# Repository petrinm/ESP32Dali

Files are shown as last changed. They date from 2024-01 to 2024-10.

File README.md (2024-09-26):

# ESP32Dali

ESP32Dali is project to interface with [DALI](https://en.wikipedia.org/wiki/Digital_Addressable_Lighting_Interface) compatible lighting devices using [ESPHome](https://esphome.io/) project. The board supports isolated communication to DALI bus as a master device and the board can also work as 18V DALI power supply from single 5V supply. ESP32Dali is a single 2-layer matchbox sized PCB to host ESP32-WROOM-32 and required interfacing components. The schematics and board files are in the `hw` folder ([KiCanvas](https://kicanvas.org/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), [pdf](https://github.com/petrinm/ESP32Dali/blob/main/hw/ESPDali.pdf)) 3D step files and printed enclosure are also available. The software is based on ESPHome project and its installation is documented in the software README.

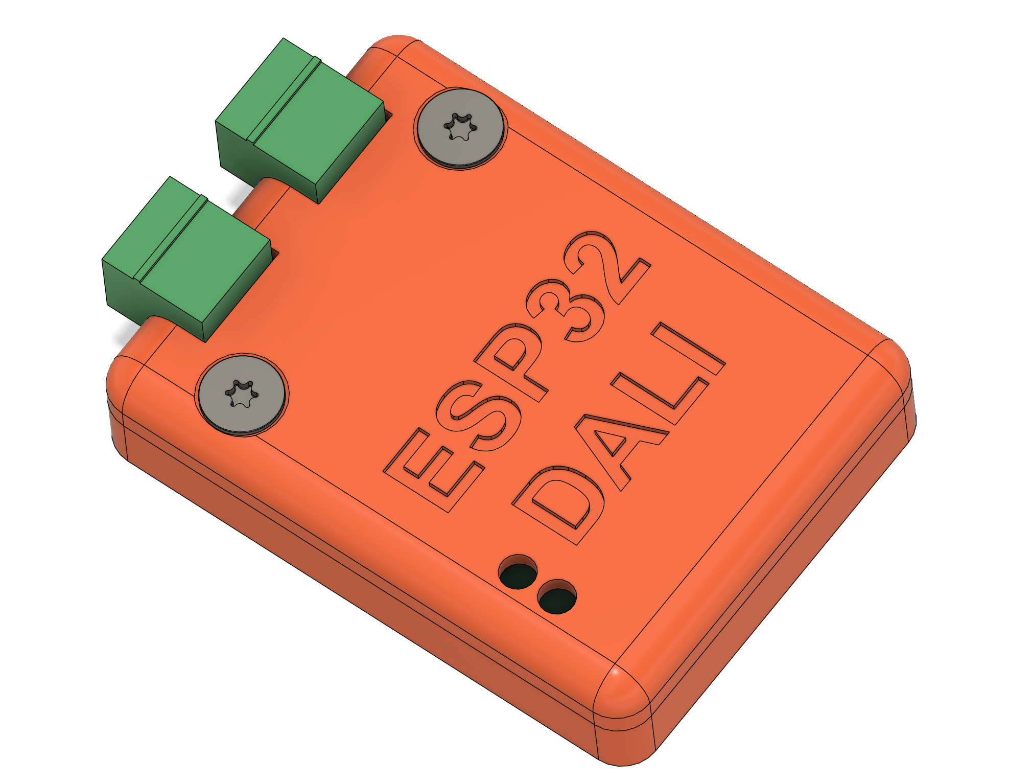
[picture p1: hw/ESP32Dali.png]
ESP32Dali

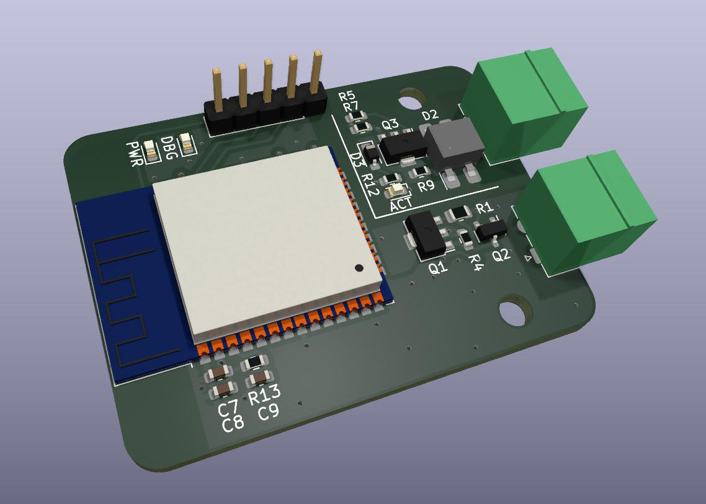
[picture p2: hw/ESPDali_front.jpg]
ESP32Dali front side

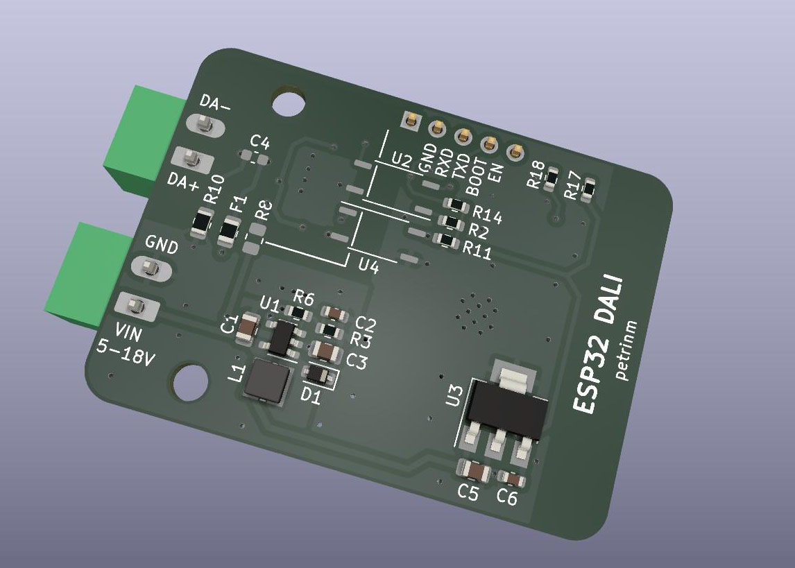
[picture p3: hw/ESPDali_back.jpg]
ESP32Dali back side


The project is licenced under MIT license.

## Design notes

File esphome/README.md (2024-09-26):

# Example configuration

```yaml
light:
  - platform: monochrome
    name: "LED strip"
    output: dali_output

dali:
  id: dali_if
  tx_pin:
    number: 17
    inverted: true
  rx_pin:
    number: 16
    inverted: true

output:
  - platform: dali
    id: dali_output
    interface: dali_if
    address: 5

```

Run
```bash
$ esphome run livingroom.yaml
```

## Installing ESP32Dali as external component

https://esphome.io/components/external_components

```yaml
external_components:
  - source:
      type: git
      url: https://github.com/petrinm/ESP32Dali.git
    components: [ dali ]
```

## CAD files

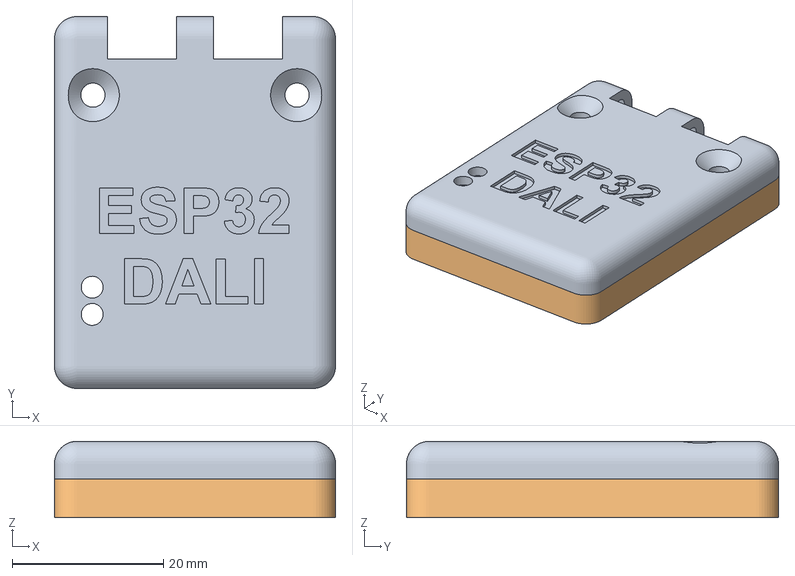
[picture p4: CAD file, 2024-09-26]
3d/Top.3mf
37.2 x 49.2 x 10.1 mm

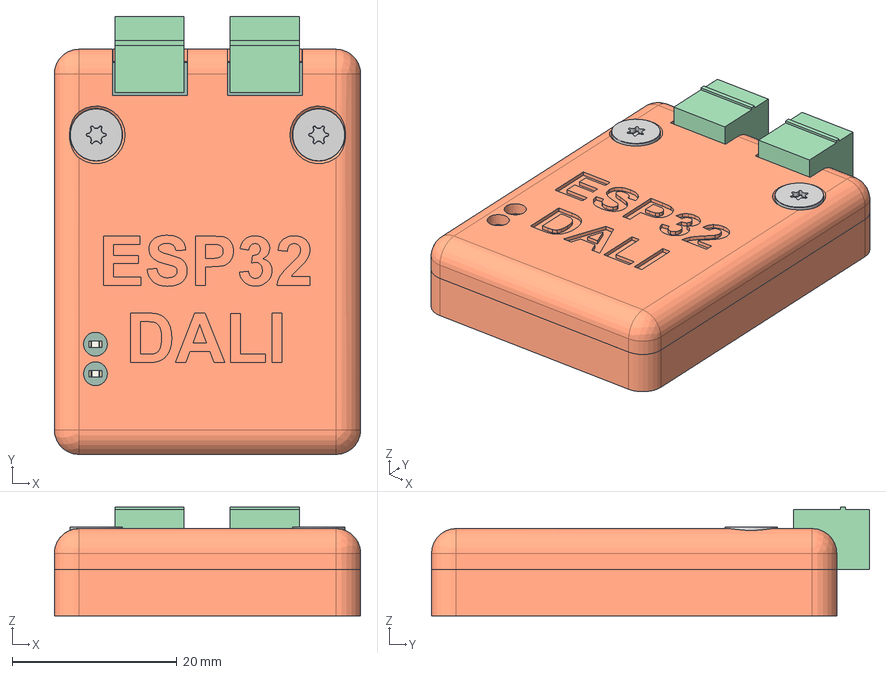
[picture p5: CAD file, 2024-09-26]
3d/ESP32Dali.step
37.2 x 53.2 x 13.2 mm
Top
ESPDali PCB
Bottom
94331A104_NO THREADS_High-Strength A286 Stainless Steel Torx Flat Hea d Screw x 2

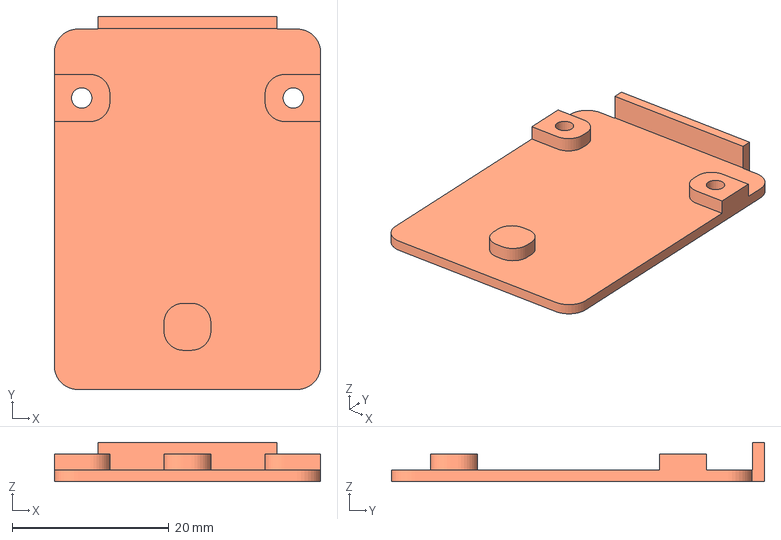
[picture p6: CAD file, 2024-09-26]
3d/Bottom.3mf
34.0 x 47.6 x 5.00 mm

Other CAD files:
3d/ESP32Dali.f3z

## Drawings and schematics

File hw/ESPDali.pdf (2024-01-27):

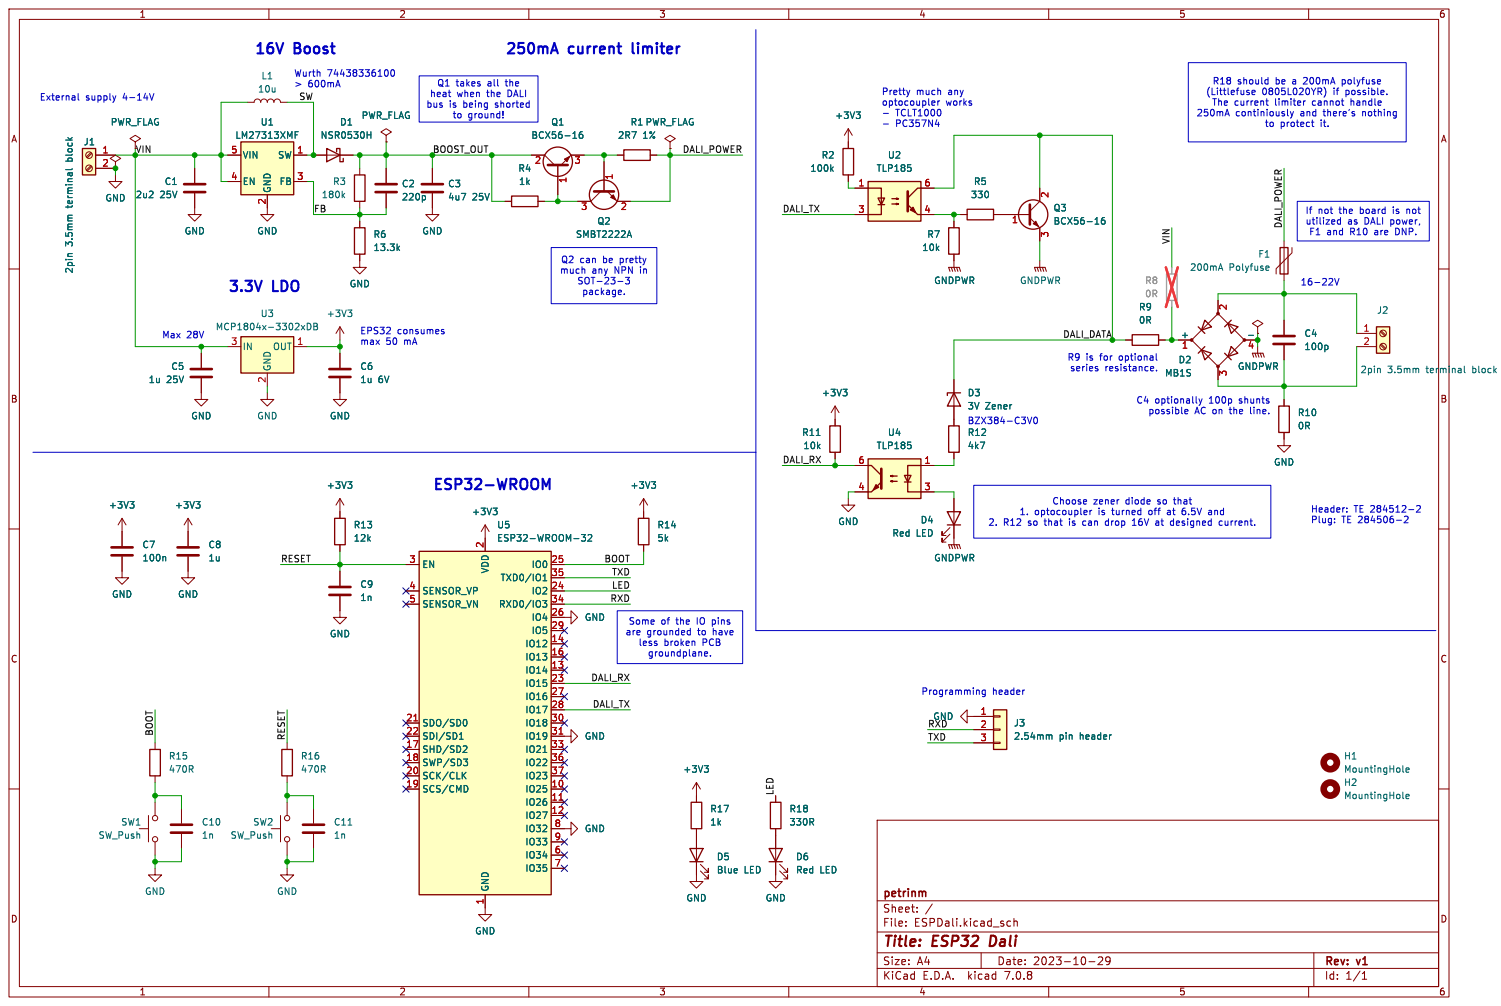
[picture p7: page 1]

2. R12 so that is can drop 16V at designed current. Q1 takes all the
heat when the DALI bus is being shorted

to protect it. Some of the IO pins are grounded to have

2 SCK/CLK 20 SDO/SD0 21 SDI/SD1 22

Id: 1/1 Title: ESP32 Dali File: ESPDali.kicad_sch Sheet: / petrinm

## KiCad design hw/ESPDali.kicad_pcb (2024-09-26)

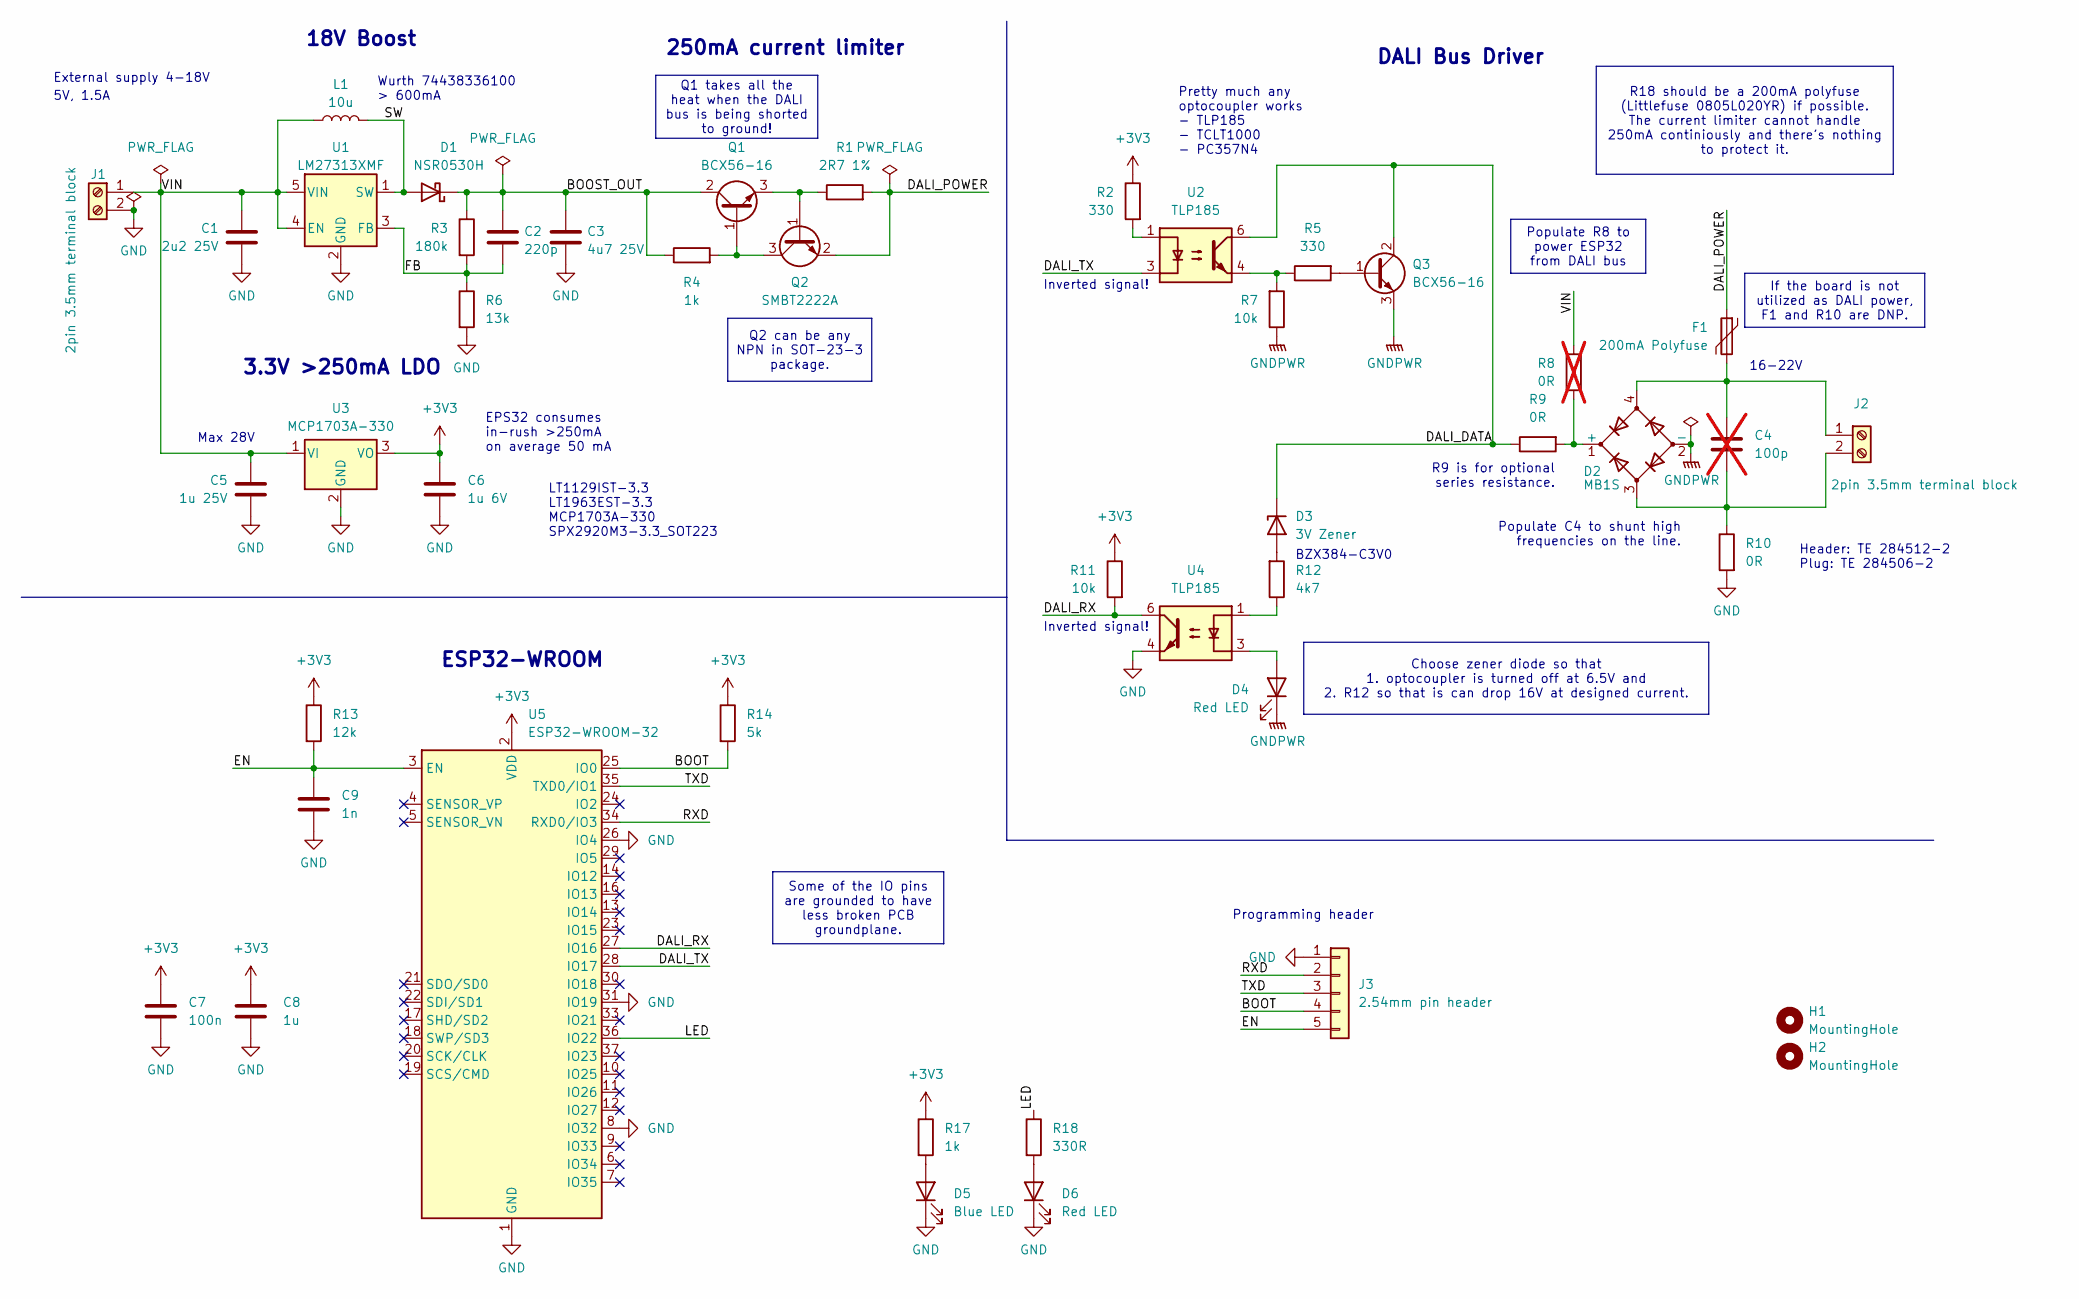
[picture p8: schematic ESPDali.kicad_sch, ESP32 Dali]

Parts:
C1: 2u2 25V; C_0805_2012Metric
C2: 220p; C_0603_1608Metric
C3: 4u7 25V; C_0805_2012Metric
C4: 100p; C_0603_1608Metric; not fitted
C5: 1u 25V; C_0805_2012Metric
C6: 1u 6V; C_0603_1608Metric
C7: 100n; C_0603_1608Metric
C8: 1u; C_0603_1608Metric
C9: 1n; C_0603_1608Metric
D1: NSR0530H; D_SOD-323
D2: MB1S
D3: 3V Zener; D_SOD-323
D4, D6: Red LED; LED_0603_1608Metric
D5: Blue LED; LED_0603_1608Metric
F1: 200mA Polyfuse; Fuse_0805_2012Metric
H1, H2: MountingHole; MountingHole_3.2mm_M3
J1, J2: 2pin 3.5mm terminal block; PhoenixContact_MC_1,5_2-G-3.5_1x02_P3.50mm_Horizontal
J3: 2.54mm pin header; PinHeader_1x05_P2.54mm_Vertical
L1: 10u; L_Wuerth_MAPI-3020
Q1, Q3: BCX56-16; SOT-89-3
Q2: SMBT2222A; SOT-23
R1: 2R7 1%; R_0805_2012Metric
R2, R5: 330; R_0603_1608Metric
R3: 180k; R_0603_1608Metric
R4, R17: 1k; R_0603_1608Metric
R6: 13k; R_0603_1608Metric
R7, R11: 10k; R_0603_1608Metric
R8: 0R; R_0805_2012Metric; not fitted
R9: 0R; R_0603_1608Metric
R10: 0R; R_0805_2012Metric
R12: 4k7; R_0603_1608Metric
R13: 12k; R_0603_1608Metric
R14: 5k; R_0603_1608Metric
R18: 330R; R_0603_1608Metric
U1: LM27313XMF; SOT-23-5
U2, U4: TLP185; SOIC-4_4.55x3.7mm_P2.54mm
U3: MCP1703A-330; SOT-223-3_TabPin2
U5: ESP32-WROOM-32

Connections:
+3V3: C6.1, C7.1, C8.1, R2.1, R11.1, R13.1, R14.1, R17.1, U3.3 (VO), U5.2 (VDD)
/BOOST_OUT: C2.1, C3.1, D1.1 (K), Q1.2 (C), R3.1, R4.1
/BOOT: J3.4, R14.2, U5.25 (IO0)
/DALI_DATA: D3.1 (K), Q3.2 (C), R9.1, U2.6
/DALI_POWER: F1.1, Q2.2 (E), R1.2
/DALI_RX: R11.2, U4.6, U5.27 (IO16)
/DALI_TX: U2.3, U5.28 (IO17)
/EN: C9.1, J3.5, R13.2, U5.3 (EN)
/FB: C2.2, R3.2, R6.1, U1.3 (FB)
/LED: R18.1, U5.36 (IO22)
/RXD: J3.2, U5.34 (RXD0/IO3)
/SW: D1.2 (A), L1.2, U1.1 (SW)
/TXD: J3.3, U5.35 (TXD0/IO1)
/VIN: C1.1, C5.1, J1.1, L1.1, R8.1, U1.4 (EN), U1.5 (VIN), U3.1 (VI)
GND: C1.2, C3.2, C5.2, C6.2, C7.2, C8.2, C9.2, D5.1 (K), D6.1 (K), J1.2, J3.1, R6.2, R10.2, U1.2 (GND), U3.2 (GND), U4.4, U5.1 (GND), U5.8 (IO32), U5.15 (GND), U5.26 (IO4), U5.31 (IO19), U5.38 (GND), U5.39 (GND)
GNDPWR: D2.2 (-), D4.1 (K), Q3.3 (E), R7.1
unnamed: D2.1 (+), R8.2, R9.2
unnamed: D3.2 (A), R12.2
unnamed: D4.2 (A), U4.3
unnamed: D5.2 (A), R17.2
unnamed: D6.2 (A), R18.2
unnamed: C4.1, D2.4, F1.2, J2.1
unnamed: C4.2, D2.3, J2.2, R10.1
unnamed: Q1.1 (B), Q2.3 (C), R4.2
unnamed: Q1.3 (E), Q2.1 (B), R1.1
unnamed: Q3.1 (B), R5.2
unnamed: R2.2, U2.1
unnamed: R5.1, R7.2, U2.4
unnamed: R12.1, U4.1

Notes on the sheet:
Q1 takes all the heat when the DALI bus is being shorted to ground!
Choose zener diode so that 1. optocoupler is turned off at 6.5V and 2. R12 so that is can drop 16V at designed current.
Q2 can be any NPN in SOT-23-3 package.
If the board is not utilized as DALI power, F1 and R10 are DNP.
Populate R8 to power ESP32 from DALI bus
R18 should be a 200mA polyfuse (Littlefuse 0805L020YR) if possible. The current limiter cannot handle 250mA continiously and there's nothing to protect it.
Some of the IO pins are grounded to have less broken PCB groundplane.
Pretty much any optocoupler works - TLP185 - TCLT1000 - PC357N4
ESP32-WROOM
16-22V
EPS32 consumes in-rush >250mA on average 50 mA
DALI Bus Driver
Populate C4 to shunt high frequencies on the line.
BZX384-C3V0
Wurth 74438336100 > 600mA
Inverted signal!
250mA current limiter
5V, 1.5A
Programming header
Max 28V
R9 is for optional series resistance.
3.3V >250mA LDO
External supply 4-18V
Header: TE 284512-2 Plug: TE 284506-2
18V Boost
LT1129IST-3.3 LT1963EST-3.3 MCP1703A-330 SPX2920M3-3.3_SOT223

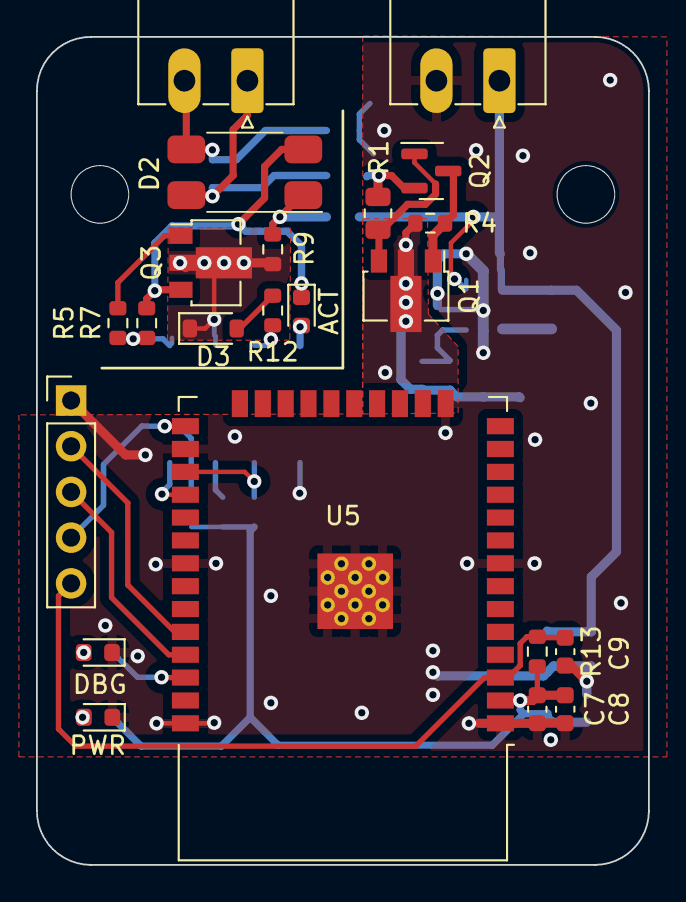
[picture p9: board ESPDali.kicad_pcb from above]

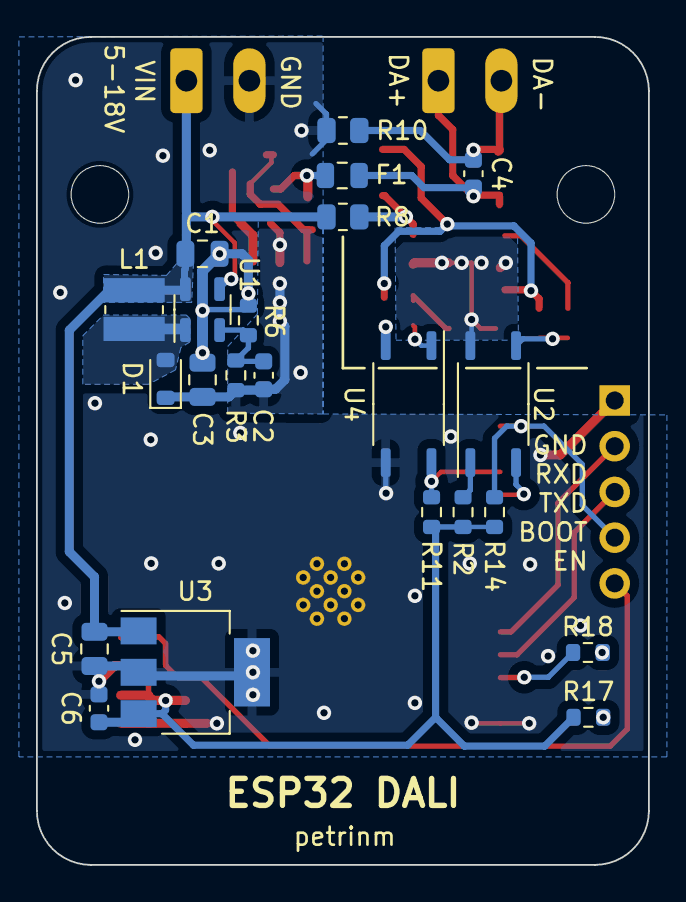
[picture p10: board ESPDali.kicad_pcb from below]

Board: 2 copper layers, 34.0 x 46.0 mm, 46 parts (22 on the bottom side), 29 nets.

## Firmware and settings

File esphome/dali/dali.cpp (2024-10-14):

#if defined(USE_ARDUINO) && defined(USE_ESP32)

#include "dali.h"
#include "dali_cmds.h"
#include "esphome/core/helpers.h"
#include "esphome/core/log.h"
#include "driver/timer.h"



namespace esphome {
namespace DALI {

static const char *TAG = "dali_interface";


/*******************************************************************************
 * Typedefs and defines
 ******************************************************************************/

#define BI_PHASE_HIGH           0b01
#define BI_PHASE_LOW            0b10
#define BI_PHASE_MASK           0b11


/*******************************************************************************
 * Define DALI timing values. One Bit on a DALI bus is
 * 833.33µs (1200 bauds) which corresponds to 2TE.
 ******************************************************************************/

#define TE            (417)                     // half bit time = 417 usec

/* Transmission timing, option to compensate for unequal physical layer delay in rising or falling edge*/
#define TE_HIGH       (TE + 0)
#define TE_LOW        (TE - 0)

#define DALI_STOP_BIT_TIME          (4*TE)
#define MIN_FORWARD_FRAME_DELAY     (22*TE)     // minimum time between two forward frames - 9.17ms ==> 22 x TE time
#define BACKWARD_FRAME_DELAY        (12*TE)     // time between forward frame and backward frame >= 7TE

#if 0 /* strict receive timing according to specification  */
  #define MIN_TE      (TE - 42)                 // minimum half bit time
  #define MAX_TE      (TE + 42)                 // maximum half bit time
  #define MIN_2TE     (2*TE - 83)               // minimum full bit time
  #define MAX_2TE     (2*TE + 83)               // maximum full bit time
#else /* More relaxed receive timing */
  #define MIN_TE      (300)                     // minimum half bit time
  #define MAX_TE      (550)                     // maximum half bit time
  #define MIN_2TE     (2*TE - (2*(TE/5)))       // minimum full bit time
  #define MAX_2TE     (2*TE + (2*(TE/5)))       // maximum full bit time
#endif

#define BACKWARD_FRAME_BIT_LENGTH     18 // two byte commands have 34 bit in total (including start bit)



/* State machine states: */
typedef enum stateTag
{
  MS_IDLE = 0,                        // bus idle
  MS_TX_SECOND_HALF_START_BIT,        //
  MS_TX_DALI_FORWARD_FRAME,           // sending the dali forward frame
  MS_TX_STOP_BITS,                    //
  MS_SETTLING_BEFORE_BACKWARD,        // settling between forward and backward - stop bits
  MS_SETTLING_BEFORE_IDLE,            // settling before going to idle, after forward frame
  MS_WAITING_FOR_SLAVE_START_WINDOW,  // waiting for 7Te, start of slave Tx window
  MS_WAITING_FOR_SLAVE_START,         // start of slave Tx window
  MS_RECEIVING_ANSWER                 // receiving slave message
} MASTER_STATE;


void inline DALI_SetOutputHigh(DALIState* driver) {
  driver->tx_pin->digital_write(false); // INVERTED!!!
}

void inline DALI_SetOutputLow(DALIState *driver) {
  driver->tx_pin->digital_write(true); // INVERTED!!!
}

bool inline DALI_GetInput(DALIState *driver) {
  return driver->rx_pin->digital_read();
}


/// Run timer interrupt code and return in how many µs the next event is expected
/* the handling of the protocol is done in the IRQ */

DALIState *gbl_driver;

static void IRAM_ATTR HOT gpio_interrupt(DALIState *driver);

static void IRAM_ATTR HOT timer_interrupt() // DALIState *driver);
{
  DALIState *driver = gbl_driver;

  switch(driver->state)
  {
    case MS_TX_SECOND_HALF_START_BIT:
      /*
       * Sending start bit
       */
      DALI_SetOutputHigh(driver);
      driver->bitcount = 0;

      // Timer auto reloads and next waits TE
      driver->state = MS_TX_DALI_FORWARD_FRAME;

      break;

    case MS_TX_DALI_FORWARD_FRAME:
      /*
       * Sending coded data bits
       */
      if (driver->forward_frame & 0x80000000)
        DALI_SetOutputHigh(driver);
      else
        DALI_SetOutputLow(driver);

      driver->forward_frame <<= 1;
      driver->bitcount++;

      // End of data bits?
      if (driver->bitcount == 32)
        driver->state = MS_TX_STOP_BITS;

      // Timer auto reloads and next waits TE
      break;

    case MS_TX_STOP_BITS:
      /*
       * Sending stop bits
       */

      // High state to free the bus
      DALI_SetOutputHigh(driver);

      // The first half of the first stop bit has just been output.
      // Do we have to wait for an answer?
      if (driver->waitForAnswer)
      {
        // Elapse until the end of the last half of the second stop bit
        timerAlarmWrite(driver->timer, 4 * TE, false);

        driver->backward_frame = 0;
        driver->state = MS_SETTLING_BEFORE_BACKWARD;
      }
      else
      {
        // No answer from slave expected, need to wait for the remaining
        // bus idle time before next forward frame.
        // Add additional 3 TE to minimum specification to be not at the edge of the timing specification
        timerAlarmWrite(driver->timer, (4 + 22 + 3) * TE, false);
        driver->state = MS_SETTLING_BEFORE_IDLE;
      }
      break;

    case MS_SETTLING_BEFORE_BACKWARD:
      /*
       * Wait for
       */

      DALI_SetOutputHigh(driver);

      // Setup the first window limit for the slave answer.
      // The slave should not respond before 7TE.
      timerAlarmWrite(driver->timer, 7 * MIN_TE, false);

      // Enable capture on both edges.
      driver->rx_pin->attach_interrupt(&gpio_interrupt, driver, gpio::INTERRUPT_ANY_EDGE);

      driver->state = MS_WAITING_FOR_SLAVE_START_WINDOW;
      break;

    case MS_WAITING_FOR_SLAVE_START_WINDOW:
      /*
       *
       */

      // Setup the second window limit for the slave answer,
      // slave must start transmit within the next 23TE window.
      timerAlarmWrite(driver->timer, 23 * MAX_TE, false);
      driver->state = MS_WAITING_FOR_SLAVE_START;

      // Next we should receive GPIO interrupts
      break;

    case MS_WAITING_FOR_SLAVE_START:
      /*
       * Receive timeout. Nothing was received
       */

      // If we still get here, got 'no' or too early answer from slave
      // idle time of 23TE was already elapsed while waiting, so
      // immediately release the bus.

      // Reset and stop the timer
      timerStop(driver->timer);

      // Disable capture
      driver->rx_pin->detach_interrupt();

      // Execution returns to Do_transfer function
      driver->state = MS_IDLE;
      break;

    case MS_RECEIVING_ANSWER:
      /*
       * Receive timeout in middle of frame
       */

      // Stop receiving
      // Now idle the bus between backward and next forward frame
      // since we don't track the last edge of received frame,
      // conservatively we wait for 23 TE (>= 22 TE as for specification).
      // Receive interval considered anyway the max tolerance for
      // backward frame duration so >22TE should already be asserted.
      timerAlarmWrite(driver->timer, 23 * TE, false);
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

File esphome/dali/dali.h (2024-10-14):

#pragma once

#if defined(USE_ARDUINO) && defined(USE_ESP32)

#include "esphome/core/component.h"
#include "esphome/core/gpio.h"
#include "esphome/core/hal.h"

#include "esphome/components/esp32/gpio.h"

#include <esp32-hal-timer.h>


namespace esphome {
namespace DALI {


struct DALIState {

  // Current state
  unsigned int state;

  // Manchester coded forward frame
  uint32_t forward_frame;

  // Bit counter
  uint32_t bitcount;

  // Flag to indicate wether a backward frame is expected
  bool waitForAnswer;

  // Received backwarf frame
  uint32_t backward_frame;

  // Transmitter pin
  InternalGPIOPin *tx_pin;

  // Receiver pin
  InternalGPIOPin *rx_pin;

  // Timer
  hw_timer_t *timer;

};

/* DT8 Colour value defines (Part 209 Table 11) */
enum QueryColourValue
{
  XCoordinate = 0,
  YCoordinate = 1,
  ColourTemperatureTC = 2,
  PrimaryNDimLevel0 = 3,
  PrimaryNDimLevel1 = 4,
  PrimaryNDimLevel2 = 5,
  PrimaryNDimLevel3 = 6,
  PrimaryNDimLevel4 = 7,
  PrimaryNDimLevel5 = 8,
  RedDimLevel = 9,
  GreenDimLevel = 10,
  BlueDimLevel = 11,
  WhiteDimLevel = 12,
  AmberDimLevel = 13,
  FreecolourDimLevel = 14,
  RGBWAFControl = 15,
  XCoordinatePrimaryN0 = 64,
  YCoordinatePrimaryN0 = 65,
  TYPrimaryN0 = 66,
  XCoordinatePrimaryN1 = 67,
  YCoordinatePrimaryN1 = 68,
  TYPrimaryN1 = 69,
  XCoordinatePrimaryN2 = 70,
  YCoordinatePrimaryN2 = 71,
  TYPrimaryN2 = 72,
  XCoordinatePrimaryN3 = 73,
  YCoordinatePrimaryN3 = 74,
  TYPrimaryN3 = 75,
  XCoordinatePrimaryN4 = 76,
  YCoordinatePrimaryN4 = 77,
  TYPrimaryN4 = 78,
  XCoordinatePrimaryN5 = 79,
  YCoordinatePrimaryN5 = 80,
  TYPrimaryN5 = 81,
  NumberOfPrimaries = 82,
  ColourTemperatureTcCoolest = 128,
  ColourTemperatureTcPhysicalCoolest = 129,
  ColourTemperatureTcWarmest = 130,
  ColourTemperatureTcPhysicalWarmest = 131,
  TemporaryXCoordinate = 192,
  TemporaryYCoordinate = 193,
  TemporaryColourTemperature = 194,
  TemporaryPrimaryNDimLevel0 = 195,
  TemporaryPrimaryNDimLevel1 = 196,
  TemporaryPrimaryNDimLevel2 = 197,
  TemporaryPrimaryNDimLevel3 = 198,
  TemporaryPrimaryNDimLevel4 = 199,
  TemporaryPrimaryNDimLevel5 = 200,
  TemporaryRedDimLevel = 201,
  TemporaryGreenDimLevel = 202,
  TemporaryBlueDimLevel = 203,
  TemporaryWhiteDimLevel = 204,
  TemporaryAmberDimLevel = 205,
  TemporaryFreecolourDimLevel = 206,
  TemporaryRgbwafControl = 207,
  TemporaryColourType = 208,
  ReportXCoordinate = 224,
  ReportYCoordinate = 225,
  ReportColourTemperatureTc = 226,
  ReportPrimaryNDimLevel0 = 227,
  ReportPrimaryNDimLevel1 = 228,
  ReportPrimaryNDimLevel2 = 229,
  ReportPrimaryNDimLevel3 = 230,
  ReportPrimaryNDimLevel4 = 231,
  ReportPrimaryNDimLevel5 = 232,
  ReportRedDimLevel = 233,
  ReportGreenDimLevel = 234,
  ReportBlueDimLevel = 235,
  ReportWhiteDimLevel = 236,
  ReportAmberDimLevel = 237,
  ReportFreecolourDimLevel = 238,
  ReportRgbwafControl = 239,
  ReportColourType = 240,
};


/* DT8 Temperature limit defines */
enum TemperatureLimit
{
  Tc_Coolest = 0,
  Tc_Warmest = 1,
  Tc_Physical_Coolest = 2,
  Tc_Physical_Warmest = 3
};


// Broadcast address
const uint8_t BROADCAST = 0x7F;


class DALIInterface: public Component {
 public:
  void setup() override;
  void dump_config() override;

  // Search ballasts
  void search();

  //--- Setup functions
  void set_tx_pin(InternalGPIOPin *tx_pin);
  void set_rx_pin(InternalGPIOPin *rx_pin);

  /* */
  void send_forward_frame(uint16_t forward_frame, bool repeat=false);
  void send_forward_frame(uint16_t forward_frame, uint16_t &response);

  /* Send Direct Arc Power Control */
  void send_dapc(uint8_t address, uint8_t power);

  /* Extinguish the lamp immediately without fading. */
  void off(uint8_t address);

  /* Increases the target illumination level */
  void up(uint8_t address);

  /* Decreases the target illumination level */
  void down(uint8_t address);

  /* Sets a group of lamps to a predefined scene */
  void goto_scene(uint8_t address, uint8_t scene);

  /* Configures the control gear's maximum output level */
  void set_max_level(uint8_t address, uint8_t level);

  /* Configures the control gear's minimum output level */
  void set_min_level(uint8_t address, uint8_t level);

  /* Configures the output level upon power-up */
  void set_on_power_level(uint8_t address, uint8_t level);

  /* Sets the fade time */
  void set_fade_time(uint8_t address, uint8_t fade_time);

  /* Sets the fade rate */
  void set_fade_rate(uint8_t address, uint8_t fade_rate);

  /* Sets the extended fade time */
  void set_extended_fade_time(uint8_t address, uint8_t fade_time);

  /* Adds the gear to scene */
  void set_scene(uint8_t address, uint8_t scene, uint8_t level);

  /* Removes one of the control gears from a scene */
  void remove_from_scene(uint8_t address, uint8_t scene);

  /* Adds a control gear to a group */
  void add_to_group(uint8_t address, uint8_t group);

  /* Removes a control gear from a group */
  void remove_from_group(uint8_t address, uint8_t group);

  /* Sets a control gear's short address */
  void set_short_address(uint8_t address, uint8_t new_address);

  /* Allows writing into memory banks */
  void enable_write_memory(uint8_t address);

  /* Write memory location */
  void write_memory(uint8_t location, uint8_t bank, uint8_t value);

  /* Read memory location */
  void read_memory(uint8_t address, uint8_t location, uint8_t bank);

  /* Set Temporary X-Coordinate (DT8) */
  void send_xcoord(uint8_t address, unsigned int coord);

  /* Set Temporary Y-Coordinate (DT8) */
  void send_ycoord(uint8_t address, unsigned int coord);

  /* Set Temporary Colour Temperature (DT8) */
  void set_cct(uint8_t address, unsigned int kelvin);

  /* Set Colour Temperarture Limit (DT8) */
  void set_tc_limit(uint8_t address, TemperatureLimit what, unsigned int limit);

  /* Query Colour value */
  uint16_t query_colour_value(uint8_t address, QueryColourValue query);

  /* Send device type */
  void set_device_type(uint8_t device_type);

protected:

  DALIState driver_;

  /* Perform Manchester coding to the forward frame payload bytes. */
  static uint32_t DALI_Encode(uint16_t forwardFrame);

  /**/
  static bool DALI_Decode(uint32_t rawData, uint16_t *pBackwardFrame);

};


}  // namespace DALI
}  // namespace esphome

#endif

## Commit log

2023-10-30 Add KiCAD temp files to .gitignore
2024-01-27 Add v1 KiCAD files
    [ESPDali.kicad_pcb, ESPDali.kicad_sch]
2024-02-16 Footprint fixes to PCB
    [ESPDali.kicad_pcb, ESPDali.kicad_sch]
2024-09-26 Update to KiCAD 8
    [ESPDali.kicad_pcb, ESPDali.kicad_sch]
2024-09-26 Add 3D files
    [Bottom.3mf, ESP32Dali.f3z, ESP32Dali.step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]
2024-10-14 Add more commands and other fixes
    [dali.cpp, dali.h]
2026-05-18 Rework DALI driver
2026-05-18 Map ESPHome transition duration to DALI fade configuration.
    Remove fadetime/faderate from DALILight YAML; add configure_fade_duration() with standard fade lookup table and extended fade for long ramps, plus gear-native transition transformer.
2026-05-18 Add optional DALI identify and commissioning button platforms.
    Implement IEC 62386-102 discovery and short-address programming in the
    driver, with ESPHome buttons for IDENTIFY DEVICE and bus commissioning.
